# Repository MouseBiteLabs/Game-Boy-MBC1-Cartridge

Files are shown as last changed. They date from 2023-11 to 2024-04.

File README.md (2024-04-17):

# Game Boy MBC1 Cartridge

This is my design of a flashable MBC1-based cartridge for the Game Boy. The MBC1 mapper was used in many of the earlier Game Boy games, such as the Super Mario Land series, the Donkey Kong Land series, Metroid II, and one of my personal favorites - the original Link's Awakening. 

This circuit board should cover most, if not all, MBC1 games. The features are as follows:

- Able to make games that use 512 KB (4 Mbit) of ROM and 256 Kbit of RAM, or 2 MB (16 Mbit) of ROM and 64 Kbit of RAM
- Compatibility with all four of the major Game Boy battery management ICs - MM1026, MM1134, BA6129, and BA6735
- The option to add battery backup to the cartridge *without* the need of the original battery management ICs - perfect for MBC1 donors that didn't have batteries in them
- Lower battery consumption compared to some of the original cartridges
- Fully compatible with the <a href="https://www.gbxcart.com/">GBxCart RW</a> so you can transfer games and save files to and from the board

assemblepic

boardscan3

All gerbers and source files can be found in this repo, as this project is fully open source. Technical documentation of the board can be found in the Technical folder.

## Important Things Before You Start

1) To use this board, you need to have an original Game Boy game that uses an MBC1 mapper chip. <a href="https://catskull.net/gb-rom-database/">You can find a list of games and their mappers here</a>. Use the search function. Please note the RAM is in bytes, not bits. Since SRAM in this repo is defined in bits, you need to convert by multiplying the number of bytes by 8.
2) You will need to remove the MBC1 from your donor cartridge for use on this board. This will require a hot air rework station or a hot plate. There's a list below of other parts you can re-use from the donor cartridge.
3) When soldering parts on, it's a good idea to put kapton tape or otherwise cover the bottom cartridge edge. You do not want to get solder on the cartridge contacts.
4) I am not responsible for any damage you do to your self or your property. Attempt this project at your own risk.
5) I do not guarantee design compatibility. You may encounter issues with certain games. There is also a chance I have made an error in the design or the BOM - if this is the case, I will do everything I can to address the problem as quickly as possible.
6) If you are using this board to make games other than for personal use, you must have permission from the originator to use and distribute any ROM images or other related material. You are responsible for making sure you adhere to any license requirements.

DO NOT use my circuit boards for profiting from stolen work - this especially includes homebrew content, ROM hacks, and using fan-made labels without permission from the originator. **Support original creators!**

## Board Characteristics and Order Information

The zipped folder contains all the gerber files for this board. The following options **must** be chosen when ordering boards for yourself.

- Thickness: 0.8mm
- Surface Finish: ENIG
- Gold Fingers: Yes, 30° chamfer

**I sell this blank circuit board on Etsy, so you don't have to buy a bunch of multiples if you don't want to.** (Click the banner!)

<a href="https://mousebitelabs.etsy.com/listing/1605236472/game-boy-cartridge-pcb-mbc1">PCB from Etsy</a> 

You can alternatively use the zipped folder at any board fabricator you like. You may also buy the board from PCBWay using this link (disclosure: I receive 10% of the sale value to go towards future PCB orders of my own):

<a href="https://www.pcbway.com/project/shareproject/Game_Boy_MBC1_Cartridge_9115d770.html">PCB from PCBWay</a>

<a href="https://oshpark.com/shared_projects/bYJcF53Z">The board is also listed on OSH Park as well.</a> **Be sure to get them in 0.8mm thickness if you order from here.**

## Required Equipment

The EEPROMs on the board needs to be programmed somehow. I recommend using the GBxCart, as mentioned. These boards are fully compatible with it, and it makes reflashing games extremely easy using <a href="https://github.com/lesserkuma/FlashGBX">lesserkuma's FlashGBX software</a>.

Alternatively, you can buy an EEPROM programmer with a TSOP adapter. The downside to this method is that you have to desolder the chip every time you want to program it. The <a href="https://flashcatusb.com/">FlashcatUSB</a> is one popular option in retro spaces.

## Battery Safety

When assembling a board, I recommend populating all the parts *except* the battery, and getting it to run initially without it. This is to make it easier to fix any solder connections that might need fixing, without having to worry about getting the battery hot. And if you need to rework anything near the battery after you've put it on the board, be safe and remove it before putting a hot soldering iron next to it.

And this should go without saying, but if you're assembling these boards with a hot plate or hot air, *do not* solder the battery on this way. You should use an iron, and keep heat off of the battery as much as possible. 

(Also check polarity!)

## Board Configurations

The board comes with four sets of jumper pads for solder bridges. SJ1 and SJ2 require you to solder bridge the middle pad either to the top pad or the bottom pad. SJ3 and SJ4 are configured by either leaving them alone or bridging them with solder. Here are the situations where you need to add solder bridges.

### RAM Size Selection (SJ1 and SJ2, or SW1)

These two sets of pads are labelled "RAM SIZE" in the middle of the board. Soldering them will configure the max RAM *and* ROM size. You must configure these pads for every game you make - do not leave them empty (if you have no SRAM, solder to the "64K" setting to maximize ROM space). <a href="https://catskull.net/gb-rom-database/">You can find a list of games here with their respective ROM and RAM sizes.</a>

- Solder bridge SJ1 and SJ2 from their middle pads to the top pads for games that have larger ROM sizes (up to 2 MB, or 16 Mbit of ROM, and up to 64 Kbit of RAM).

- Solder bridge SJ1 and SJ2 from their middle pads to the bottom pads for games that have larger RAM sizes (up to 512 KB, or 4 Mbit of ROM, and up to 256 Kbit of RAM).

- SJ1 and SJ2 must be soldered in the same direction.

- The footprint of these selection pads should allow for a DPDT switch, part number CAS-220A1, to be placed on these pads instead of having to bridge the pads with solder.



### Using an MM1134 or BA6735 for U4 (SJ3)

Bridge the jumper SJ3 if you have either an MM1134 or BA6735 for U4, specifically. Any other battery management IC must leave SJ3 unsoldered.

### Making Games Without RAM (SJ4)

If your game does not have RAM on it (and therefore, you don't need the battery management IC U4), bridge SJ4 with solder. **Do not** bridge SJ4 if you are using U5 (TPS3613) instead of U4.

## Test Points and Final Checkout

On the back of the board are five test points. Here's where they are connected:

- TP1: SRAM supply voltage
- TP2: Battery voltage (after R1)
- TP3: Battery voltage (positive terminal of battery)
- TP4: Ground
- TP5: VCC input voltage

After you assemble your game, you should measure the current out of the battery. But first, you should program it with the GBxCart, or if you programmed the EEPROM separately, put it into a Game Boy and cycle power once. Then, flip the PCB upside down on a non-conductive surface (not your leg), and set your multimeter in DC millivolts (or volts). Put the positive probe on TP3 and the negative probe on TP2. If you used a 10kΩ for R1, as indicated in the BOM, you should read a voltage in the single of millivolts. If you have something much higher, especially voltages above 30mV, then you likely have an issue or short circuit on the board somewhere.

**Note: You need to power up the game at least once before battery currents will make sense - the battery management ICs can start up in an unknown state before applying main power to the board.**

To estimate battery life, see <a href="https://github.com/MouseBiteLabs/Game-Boy-MBC1-Cartridge/tree/main/Technical#estimating-battery-life">this section in the Technical Design Document</a>, or for more in-depth analysis, <a href="https://hackaday.io/project/11864-tritiled/log/72554-determining-maximum-runtime-176-to-202-years-cr2032">this Hackaday post</a>.

### Why not FRAM?

This board is only suitable for using SRAM. One downside to SRAM, if you haven't figured it out yet, is that you need a battery to keep the SRAM powered on even when the game is turned off. So eventually the battery will die, and your save data is lost. Some people have used FRAM, or Ferroelectric RAM, to keep save data around even after the battery dies (specifically, the popular part that's used for FRAM carts is the FM18W08). But, using this FRAM chip has a handful of downsides, and the benefit of keeping save data after the battery dies *in my opinion* does not outweigh the cons, which are as follows:

1) Quality, new stock, 5V tolerant FRAM is expensive ($12+ per part).
2) Cheaper FRAM chips from eBay or Aliexpress are notoriously flaky (anecdotally, ~50% success rate).
3) FRAM memory access requires different chip select timing than SRAM, and the Game Boy expects SRAM, so it is not natively compatible with FRAM carts. The Gameboy Color specifically cannot (easily) be made to properly access FM18W08 chip. You *can* use an OR gate and add the CLK on the cart edge to try to achieve the necessary timing, but it only works (properly) for DMG/MGB/SGB, not the GBC. It usually *works* in practice for GBC, but it's technically a datasheet violation and can potentially cause issues in edge cases. <a href="https://github.com/Gekkio">(Thanks to gekkio for pointing this out!)</a>

Brand new SRAM chips are ~$3, and having the SRAM footprint also allows you to use SRAM from an original cart if desired. You will *easily* get more than a decade of life running on a battery. You're already assembling this cartridge; you can dump the save and replace the battery before then!

Note that this isn't to throw shade at any FRAM-based carts, but for me personally, it's more trouble than it's worth.

## Board Fitment

The shape of this board was originally meant to mimic original Game Boy circuit boards as closely as possible (v1.3 and earlier). Unfortunately, when placed in some aftermarket Game Boy cartridge shells (like those from Cloud Game Store), the circuit board has a lot of freedom to rotate around the main screw hole in the bottom-middle of the cartridge. This can cause misalignment when you put it in a Game Boy, which can cause a game to either not load properly (garbled Game Boy logo) or shut off the Game Boy because of a short circuit. This isn't *dangerous* or anything, just annoying.

In order to make the boards fit nicer in any kind of shell, for v1.4 I added extended tabs of circuit board material to the edges of the cartridges to keep it from rotating too much in shells, which was suggested to me by <a href="https://github.com/orangeglo">orangeglo</a>! (Thanks!)

If you're having trouble fitting the circuit board into a shell, because the tabs interfere with the cart edges, you can safely sand or trim them down as there is no copper within the tabs themselves. The only shell that appears to require any kind of trimming are Kitsch-Bent shells.

## Bill of Materials (BOM)

Your parts list will vary depending on the game you are trying to make, and what chips you have for the battery management (if any). **You cannot use both U4 and U5 - you must choose one or the other.** U4 comes from a donor cartridge, and U5 is a readily available aftermarket option.

Please carefully review the parts you need for the board you are trying to make. Do not add any parts to your build that don't appear in the column for the game you are making. This means you *cannot* populate every component on the board at the same time.

| Reference Designators | Value/Part Number | Package | Description | No save carts | Save carts with MM1134 or BA6735 | Save carts with MM1026 or BA6129 | Save carts without donor U4 chip | Source |
| --- | --- | --- | --- | --- | --- | --- | --- | --- |
| B1 | CR2032, CR2025, CR2016 | CR2032 | Backup Battery | | x | x | x | [https://mou.sr/3SeAzfT](https://mou.sr/3SeAzfT) |
| C1 | 0.1uF | 0603 | Capacitor (MLCC) | x | x | x | x | [https://mou.sr/3ENc15O](https://mou.sr/3ENc15O) |
| C4 | 0.1uF | 0603 | Capacitor (MLCC) | | x | x | | [https://mou.sr/3ENc15O](https://mou.sr/3ENc15O) |
| C5 | 0.1uF | 0603 | Capacitor (MLCC) | | x | x | x | [https://mou.sr/3ENc15O](https://mou.sr/3ENc15O) |
| C6 | 10uF | 0603 | Capacitor (MLCC) | | x | x | x | [https://mou.sr/3mZtSkF](https://mou.sr/3mZtSkF) |
| C7 | 0.1uF | 0603 | Capacitor (MLCC) | x | x | x | x | [https://mou.sr/3ENc15O](https://mou.sr/3ENc15O) |
| C8 | 0.1uF | 0603 | Capacitor (MLCC) | | | | x | [https://mou.sr/3ENc15O](https://mou.sr/3ENc15O) |
| Q1 | 2N7002 | SOT-23 | N-Channel FET | | | | x | [https://mou.sr/3rgfh6J](https://mou.sr/3rgfh6J) |
| Q2 | 2N7002 | SOT-23 | N-Channel FET | | | x | | [https://mou.sr/3rgfh6J](https://mou.sr/3rgfh6J) |
| R1 | 10k | 0603 | Resistor | | x | x | x | [https://mou.sr/3riR7IH](https://mou.sr/3riR7IH) |
| R3 | 49.9k | 0603 | Resistor | | x | x | x | https://mou.sr/3Q3NRZO |
| R4 | 49.9k | 0603 | Resistor | | x | x | x | https://mou.sr/3Q3NRZO |
| R5 | 49.9k | 0603 | Resistor | x | x | x | x | https://mou.sr/3Q3NRZO |
| R6 | 49.9k | 0603 | Resistor | x | x | x | x | https://mou.sr/3Q3NRZO |
| R7 | 10k | 0603 | Resistor | | | x | | [https://mou.sr/3riR7IH](https://mou.sr/3riR7IH) |
| R8 | 10k | 0603 | Resistor | x | x | x | x | [https://mou.sr/3riR7IH](https://mou.sr/3riR7IH) |
| R9 | 130k | 0603 | Resistor | | | | x | https://mou.sr/3MjXliy |
| R10 | 49.9k | 0603 | Resistor | | | | x | https://mou.sr/3Q3NRZO |
| U1 | 29F016, 29F032, 29F033 | TSOP-48, TSOP-40 | Flash EEPROM | x | x | x | x | AliExpress or eBay |
| U2 | MBC1 | SOP-24 | MBC1 Mapper | x | x | x | x | Donor MBC1 Game Boy cartridge |
| U3 | AS6C6264, AS6C62256 | SOP-28 | SRAM | | x | x | x | [https://mou.sr/450klcY](https://mou.sr/450klcY) |
| U4 | MM1026, MM1134, BA6129, BA6735 | SOIC-8 | Battery Management | | x | x | | Donor Game Boy cartridge |
| U5 | TPS3613 | MSOP-10 | Battery Management | | | | x | https://mou.sr/45Ir2kh |

*Note that C9 - C11 footprints are only included on the board for strange edge cases that may require them sometime in the future; do not populate! See the technical design document for more information.*

### Usable Donor Cartridge Parts

You can use a few parts from the donor cart on the new board to save some money. Note that you will generally get better reliability with new parts as opposed to old ones. For example: I have seen failed RAM chips from donors in the past.

1) **U2: MBC1** - This one is required
2) **U3: SRAM** - You can use this part *only if* the game you're making uses the same or less amount of RAM that the donor cartridge does
3) **U4: Battery Management IC** - Using this is probably preferred over the TPS3613 because it'll save you money and parts to put on

You could probably transfer over most of the 0.1uF capacitors but they're pretty cheap anyway, so I generally just recommend buying new resistors and capacitors.

### Capacitors C9 to C11

If you want to experiment with the capacitors C9 to C11, see this info below. **Be aware that adding these components in some of my tests actually ***stopped*** games from working, so again, assume that if you have a problem it lies elsewhere first, because it almost certainly does.**
- C9 is a capacitor connected nearby the MBC1's /WR pin to GND. These were populated on some cartridges, and have a value of approximately 1 nF (0.001 uF).
- C10 is a capacitor connected nearby the MBC1's /RESET pin to GND. A spot for this capacitor was included on some MBC1 carts, but I cannot locate an instance of it actually being used when looking through the gbhwdb. I don't actually know what value this capacitor would need to be, so I am guessing 1 nF.
- C11 is a capacitor that I have added that was not used on any original Game Boy board. It connects to the SRAM's /CE pin, bypassing to GND. I have added this in the event incompatibilities arise with newer SRAM chips that have much faster speeds than older SRAM chips. This was a problem I encountered on some of my NES cartridges, so this is here just in case, but I have not found an instance where it's required.

## Things to Remember

- The footprint for the EEPROM is specifically for 29F016 - it has 48 pins. However, 29F032 and 29F033 are only 40 pin devices. They still work fine on the board though - place them in the center of the footprint, and leave the outer two pins on each corner empty
- The 29F016, 29F032, and 29F033 have been known to occasionally be defective upon arrival. They're either used, or new old stock, and usually only available from AliExpress.
- The footprint for the battery can fit a CR2032, CR2025, or CR2016 with solder tabs. The only difference is the mAh capacity (larger number = longer life). If you get Panasonic tabbed batteries, you may have to trim the battery tabs to make them fit on the footprint.
  - For untabbed coin cells, you can find battery retainer adapters online, <a href="https://retrogamerepairshop.com/products/hdr-game-boy-game-battery-retainer?variant=40511013290156">like this one,</a> but only for board revision v1.4. It will not fit on earlier revisions.
- For battery management, use either U4 *or* U5 and supporting components. **Do not** use U4 and U5 simultaneously on one board. They will interfere with each other.
- Generally, ROM sizes are conveyed in terms of kilo**bytes** and mega**bytes** (KB, MB). RAM size is usually conveyed in terms of kilo**bits** or mega**bits** (Kbit, Mbit). You can convert Kbit and Mbit to KB and MB by dividing Kbit or Mbit by 8. For example, 256 Kbit = 32 KB.
- You only need to provide ROM and RAM chips that have at least *or greater* the size of the game you are trying to make. That means you can use a 256 Kbit SRAM chip for a game that only requires 64 Kbit of RAM!

## Labels

If you want a Bucket Mouse branded label for your cartridge, look no further than <a href="https://krizdingus.com/mousebitelabs/">krizdingus's designs</a>. Special thanks to Kris for designing these, they look awesome! (If you are going to order/print these, use the high-res images hosted on his website, and *keep the labels for personal or non-commercial use only.*)



## Revision History

### v1.4
- Reduced cart edge by 0.1 mm for better fitment
- Adjusted battery placement to support more battery holders
- Added tabs on the board edges to allow the circuit board to fit better in aftermarket cartridge shells

### v1.3
- Extended cart edge down by 0.25 mm for better fitment
- Added OSHW logo and "SUPPORT ORIGINAL CREATORS!"

### v1.2
- Replaced non-donor battery management circuitry with a TPS3613-based circuit for smaller BOM and easier routing

### v1.1
- Moved all parts on the top down to allow for compatibility with DMG-style shells
- Rotated battery for more space
- Widen SRAM footprint for easier soldering
- Renamed some reference designators for consistency between designs
- Changed silkscreen for clarity

### v1.0
- Prototype revision

## Resources and Acknowledgements

- <a href="http://www.devrs.com/gb/files/hardware.html">Jeff Frohwein's GameBoy Tech Page</a>
- <a href="https://gbhwdb.gekkio.fi/">Game Boy Hardware Database</a>
- <a href="https://catskull.net/gb-rom-database/">Nintendo Gameboy Game List</a>
- <a href="https://wiki.tauwasser.eu/view/MBC1">Tauwasser's Wiki</a>
- <a href="https://www.gbxcart.com/">insideGadgets discord server for GBxCart RW compatibility requirements</a>
- <a href="https://github.com/lesserkuma/FlashGBX">Lesserkuma's FlashGBX software</a>
- <a href="https://www.alldatasheet.com/datasheet-pdf/pdf/99104/MITSUBISHI/MM1026.html">System Reset IC Datasheet</a>
- <a href="https://www.ti.com/lit/ds/symlink/tps3613-01.pdf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">TPS3613 Datasheet</a>
- Board outline modified from <a href="https://tinkerer.us/projects/homebrew-gameboy-cartridge.html">Dillon Nichols's Homebrew Gameboy Cartridge project</a>
- Thanks to <a href="https://github.com/orangeglo">orangeglo</a> for his suggestion of adding spacers around the board edge for better fitment in aftermarket cartridges
- Some components from <a href="https://github.com/adafruit/Adafruit-Eagle-Library">Adafruit's Eagle parts library</a>
- Some components from <a href="https://www.snapeda.com/">SnapMagic</a>
- Thank you to <a href="https://github.com/Gekkio">gekkio</a> for their deep Game Boy knowledge resources, and for collaboration in demystifying some of the design choices on Game Boy cartridges
- Thanks to the awesome members of the <a href="https://moddedgameboy.club/">Modded Gameboy Club</a> for their feedback and support during the entire project development

## License

<br />This work is licensed under a <a rel="license" href="http://creativecommons.org/licenses/by-sa/4.0/">Creative Commons Attribution-ShareAlike 4.0 International License</a>. You are able to copy and redistribute the material in any medium or format, as well as remix, transform, or build upon the material for any purpose (even commercial) - but you **must** give appropriate credit, provide a link to the license, and indicate if any changes were made.

©MouseBiteLabs 2023

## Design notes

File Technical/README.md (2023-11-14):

# Technical Design Document 

This write-up will serve as an attempt of explaining some of the features on this cartridge. I won't go into heavy detail about the functionality of the MBC1, but I will attempt to explain some higher level functions and the reasoning behind the circuit.

Please correct me on any information I may have gotten wrong.

## Schematic



## Cart Edge Pins

Very briefly, I will categorize the different pins on the 32-pin cartridge edge connector.

- Pin 1 and pin 32 are VCC and GND, respectively.
- Pin 2 is the CLK or PHI pin. These are not used on the MBC1 cartridge.
- Pin 3 is the /WR pin, pin 4 is the /RD pin, pin 5 is the /CS pin. These signals partially determine when data is read from the ROM or when data is read/written to the RAM.
- Pins 6 through 21 are the address pins A0 through A15.
- Pins 22 through 29 are the data pins D0 through D7.
- Pin 30 is the /RST (or reset) pin. When this pin is low, the Game Boy will cease operation.
- Pin 31 is a generally unused pin in Game Boy cartridges, but here it is connected to the EEPROM's /WE pin for compatibility with the GBxCART RW.

## MBC1 - Memory Bank Controller

The MBC1 is a pretty simplistic memory mapping chip. I won't go into detail how it operates, because you can find sufficient explanations from <a href="https://wiki.tauwasser.eu/view/MBC1">Tauwasser's website</a>, among others. A high level explanation is that it is used to expand the addressable memory of a Game Boy cartridge. The RA14-RA18 and AA13-AA14 outputs are used to access higher memory banks on the ROM and RAM chips. It also has ROM and RAM chip select outputs to control data access on the ROM and RAM chips, though only the RAM /CS output is commonly used.

Further sections will provide more context for some of the MBC1 pins and the logic of how they are connected.

## ROM and RAM

The connections to the address and data pins here are mostly self-explanatory. However, the upper address pins are controlled by the MBC1.
- A14 through A18 on the ROM chip are controlled by the RA14 to RA18 outputs from the MBC1.
- A19 and A20 on the ROM, and A13 and A14 on the RAM, are both controlled by the MBC1's output pins 6 and 7 - but you can only select one set of pins, not both!
  - This means you can use the MBC1 for games with 512 KB (4 Mbit) of ROM space and 256 Kbit of RAM space, *or* 2 MB (16 Mbit) of ROM space and 64 Kbit of RAM space. On my cart, this is selected with SJ1 and SJ2.
  - R3 through R6 on my cart are pull-down resistors for asserting the unused set of two pins to known states to prevent unwanted behavior.
    - In 64K SRAM mode: R3 will pull pin 26 on the SRAM to the CS_OUT pin (which connects to the MM chip CS output pin or the /RESET output pin of TPS3613). On 64K SRAM chips, this is the CE2 pin, and it's normally wired this way on regular carts for low-power data retention mode. If you use a 256K SRAM chip instead, then this is the A13 address pin, and will go unused if using it in 64K mode.
    - In 64K SRAM mode: R4 will pull pin 1 on the SRAM to GND. This is NC on 64K SRAM chips, and A14 on 256K SRAM chips which will be unused in 64K mode.
    - In 256K SRAM mode: R5 and R6 will pull the upper unused address pins of the EEPROM to GND.



Other pins include: 

- The ROM's /CE pin is controlled by the A15 address pin and the /OE pin is controlled by the /RD pin on the cart edge (pin 4).
- The ROM's /WE pin, which was not on original cartridges, is connected to pin 31 on the cart edge for programming via the GBxCART RW as previously mentioned.
- The RAM's /OE pin is connected to the /RD pin on the cart edge (pin 4).
- The RAM's /WE pin is connected to /WR on the cart edge (pin 3).
- The RAM's /CE pin requires a bit of explanation, which will be covered in a later section.

## Battery Management and Data Retention Considerations

Ensuring current coming out of the battery is as minimal as possible while the Game Boy is turned off is crucial for long-lasting save data. The higher the current, the lower the battery life! But we need to do this without breaking compatibility with normal operation. So here are the things we need to keep in mind:

1) SRAM must have continuous power to retain save data.

2) Data on the SRAM must be accessible during normal gameplay.

3) The number of battery-powered current-consuming components should be minimized, and those that are powered must use as little current as possible.

4) Operation while the voltage is ramping down after turning off the power switch must be restricted to prevent junk data from being written to cartridge RAM.

Original MBC1 carts manage all of this with U4, which was typically MM1026 or the equivalent BA6129. The MM1134 or the equivalent BA6375 can also be used. I'll go over the functional requirements here, and for convenience, I'll be using the MM numbers when talking about them.

### SRAM Operational Background

For most Game Boy games, there were two main sizes of SRAM chips used - 64 Kbit and 256 Kbit (further refered to as just 64K or 256K). The pinouts of these two types of chips are nearly identical: 



The big differences are the number of address pins and the number of chip enable pins. The 64K chip has 13 address pins and two chip enables (/CE and CE2), and the 256K chip has 15 address pins and one chip enable (just /CE). The additional address pins on the 256K SRAM gives it more memory, but one of the chip enable pins had to be sacrificed to accommodate this. This is kind of important, because the chip enable pins influence two main things - they tell the chip when data is being accessed, *and* how much current the chip is drawing during standby. For 64K SRAM chips, that's pretty easy - use one chip enable pin for data access, and the other for data retention mode. But for 256K SRAM, you have to do both of those functions at once. Look at the requirements for the low "data retention current" on the AS6C6264 datasheet and the AS6C62256 datasheet:



For 64K, /CE needs to be at VCC, *or* CE2 needs to be at GND for the current to be minimized. For 256K, /CE needs to be at VCC, full stop (in this case, VCC is whatever voltage appears on the SRAM's VCC pin, so when power is off that's the battery voltage). That's not super convenient if the power is off - something needs to make the /CE pin go to VCC, which means whatever that something is better not be pulling a lot of current, lest we lower our battery life.

On original MBC1 cartridges, games that have 64K SRAM used the MBC1 for controlling the /CE pin for data access, and U4 (MM1026) for keeping CE2 at GND when power was off. But for 256K SRAM, that CE2 pin wasn't available anymore. Instead, if a cartridge had an MM1026 chip for battery management, the MBC1 was powered via of the battery as well, and had internal logic to keep /CE logic high when disabled. The MM1026 has a /CE output as well that will pull the output up to the battery voltage, however it *does not* have a way to allow the /CE pin to be accessed during normal gameplay. So the MBC1 needs to take care of both functions, but since it's powered from the battery when power is off, that means the battery life would be impacted. I don't know how much current the MBC1 pulls from the battery for games that had 256K SRAM, but I imagine it probably wasn't a whole lot - I would still expect 64K SRAM games to last longer though.

*Wouldn't it be great if there was some version of this MM chip that utilized some kind of function that combined regular access of the 256K SRAM's /CE pin but also keep it pulled up to battery voltage when power was shut off for low data retention currents without having to power the MBC1 on the battery as well? ..... Foreshadowing is a literary device in whi ---*

On my custom MBC1 board, I implement a method of accessing the RAM /CE pin *and* keeping it in a low power state, without needing the MBC1 to be powered by the battery. This can be done with just an MM1134, an MM1026 and extra parts, or completely new off-the-shelf components without the need for a donor. But before covering that, let's talk about the other important part of the battery backup system - how to properly and safely manage shifting between console power to battery power.

### Reset IC - MM1026

When you turn the power switch off on a DMG, the voltage on the VCC supply will ramp down. However, the DMG CPU requires 5 V to operate properly. A sufficiently lower voltage supplying the CPU may cause erroneous operation on the I/O pins of the CPU, even for a brief period of time. This can corrupt data stored on the SRAM of the game cartridge, say if the CPU accidentally writes junk data to part of the memory. This is bad! 

In order to prevent this, cartridges that have battery-backed SRAM on them use the battery management chip U4 to shut down operation of the CPU on pin 30 of the cart edge - the /RST (or /RESET) line. Asserting this to GND will stop all operation on the I/O pins, preventing corruption from occuring. According to the MM1026 datasheet, the /RESET output and CS output pins will be GND whenever voltage on the VCC pin is below 4.2V.

*Please note that the MM1026 has a /RESET output pin, but this is not the same as the Game Boy CPU /RESET input, the MBC1 /RESET input, or the cart edge /RST pin 30! I will call the MM1026's pin 2 the "Reset output pin" from now on for clarity.*



But that's not all the MM chip does. It also is used to pull the MBC1's /RESET input to GND as well. This is especially important for original Game Boy MBC1 carts with 256K SRAM that needed the MBC1 to be powered from the battery, as keeping this pin off will (assumedly) keep current draw of the MBC1 to a minimum. Furthermore, pulling this pin to GND also causes the MBC1 to assert the SRAM's /CE pin high to keep the SRAM in a low power state.

### Reset IC - MM1134

The MM1134 is nearly identical to the MM1026, with one distinct difference. There is one extra input that was previously an unconnected pin on the MM1026 - the /Y input. This input is intended to be used with a RAM /CE signal. It controls the /CS output (pin 5) on the MM1134. See the schematic and timing diagram below:



Essentially, the /CS output will follow the /Y input, *unless* VCC is below the 4.2V power-off threshold. Then, /CS will be pulled to VOUT (the combination of VCC and VBAT). Hey, this is great, because it means we can control that pesky 256K SRAM /CE pin *and* put it in a low power state when the power shuts off!

*Note: If you ground the /Y input, then the MM1134 will act exactly like an MM1026.*

On the gbhwdb, there are only a few cartridge PCBs that use an MM1134 (the BA6735 equivalent, specifically) - DMG-DECN-20 and DMG-DGCU-10 - but these boards use 64K of SRAM, so this extra /Y pin goes unused. 

### Open Collector Requirements on CPU /RESET Input

One minor, but important, note that drives a few design choices - there are actually two outputs on the MM1026/MM134 that go low when power is below 4.2 V. One of them is open collector (pin 2, the "Reset output"), and one is instead driven high by an internal transistor or pulled low by an internal pull-down (pin 3, the "CS output"). This is important because it means *you cannot safely use the CS output pin to control the Game Boy's /RESET line.*



On the DMG, the CPU's /RESET input is also connected to half of the power switch. When the switch is fully turned off, the /RESET input is pulled to GND directly.



*[Image adapted from <a href="https://github.com/Gekkio/gb-schematics/blob/main/DMG-CPU-06/schematic/DMG-CPU-06.pdf">gekkio's DMG CPU board schematic</a>]*

This means that to ensure no damage is done to the battery management chip, any output connected to the Game Boy's /RESET input must be **open collector**. Open collector outputs can either float their output, or (in this case) pull it to GND - reference the "Pin 2 Reset Output" schematic above. That means pulling it to GND with the power switch won't damage anything internal to the chip, it will just safely bypass the pin's function.

But, in the case of pin 3 on the MM chips, the "CS output" pin, imagine a scenario where the power switch was turned off, but the capacitors on the board have not yet discharged down to 0V. This means there'd still be some residual voltage on the VCC net. But, the CS output pin is connected to VCC via the transistor internal to the chip, and if VCC hasn't dropped far enough, then this would still be pulled high to VCC. So if you had connected pin 3 to the /RESET input on the Game Boy, in this scenario, there would be a path from VCC on the MM's supply pin, *through* the transistor on pin 3, through the power switch on the DMG, to GND - short circuiting the capacitors on the board. This means that for a moment, the internal transistor driving pin 3 would experience a surge of current. Since the output is not designed to do that, it could cause damage to the part. So let's avoid that situation!

In conclusion, any output connected to the /RESET net on the Game Boy *must* be open collector.

*On the GBC, they added a chip that pulls the /RESET line to GND through an open collector output whenever the voltage on VCC drops below 3.5 V, instead of using the power switch to ground the input. If the DMG had this, maybe Nintendo wouldn't have needed these MM chips but could use something a bit simpler. But we must design cartridges with DMG compatibility in mind!* 

## Battery Management Implementation Options

Ok, with the background taken care of, I'll talk about how my MBC1 board manages all of this, and the different compatibility options. If you reference the schematic above, you will see three options for games that use SRAM:
1) MM1134 ("Group A" components)
2) MM1026 ("Group A" and "Group C" components)
3) No donor MM chip ("Group B" components)

### Using an MM Chip

For reference again, here is a pinout diagram of the MM1026 and MM1134.



And here is the section of the schematic for using one of these chips ("Group A" components).



#### Creating the Battery-Backed Power Supply

The VOUT pin is a combination of the VCC and VBAT pins. VCC is connected to the Game Boy's 5V supply, and VBAT is connected to the battery (through a current-limiting resistor). When VCC drops below 3.3V during power-down, the MM chip switches VOUT to be supplied by VBAT instead of VCC. Conversely, when it passes above 3.3V during power-on, the MM chip switches VOUT to be supplied by VCC instead. This guarantees constant power to the SRAM to keep save data retained at all times, assuming the battery is not dead.

#### Reset Pin Management

Because anything connected to the /RESET input pin on the cart edge must be open collector, the open collector output of the MM chip, pin 2, is connected to the /RESET cart edge pin (pin 30). The MBC's /RESET input, pin 10, is connected to the driven CS output of the MM chip, pin 3.

#### Controlling the SRAM /CE Pin (MM1134)

The RAM_/CS output of the MBC1 is connected to the /Y input (pin 7) of the MM1134, and if SJ3 is bridged to connect it to RAM_/CS_G (as it should be when using an MM1134), the /CS output (pin 5) will be connected to the SRAM /CE input. As explained earlier, the state of the /CS output of the MM1134 is the same as the /Y input, unless VCC is below 4.2V, in which case the /CS output is pulled up to the VOUT voltage to satisfy low-current data retention requirements of the SRAM.

#### Controlling the SRAM /CE Pin (MM1026)

Because the MM1026 does not have the gated /CS output functionality, and the MBC1 is not powered by the battery on my cart design, we need to add the function back with some external components, which I have labelled as "Group C" components in the schematic.



As a reminder: RAM_/CS connects to the MBC1's RAM_/CS output pin, RAM_/CS_G connects to the SRAM's /CE input, and VCC_SRAM connects to the MM1026 VOUT pin.

- When the CS output is driven low (when VCC is below 4.2V), conduction between the drain and source of Q2 will be off; the RAM_/CS_G net will be pulled up to the battery-backed voltage via R7, no matter what RAM_/CS is doing.
- When the CS output is driven high (when VCC is above 4.2V), conduction between the drain and source of Q1 is allowed; RAM_/CS_G will follow the RAM_/CS output, which will allow the MBC1 to control the SRAM /CE input.

Thus, this circuit essentially adds the MM1134's gated /CS output functionality back into the circuit.

### Using Brand New Components

If you do not have one of these MM chips, as you can only typically get them from donor Game Boy cartridges and not all games use them, you can achieve the same results using commercially-available components. In order to do so, you need to populate "Group B" components which features the TPS3613 - a Texas Instruments chip that is almost identical to the MM1134, with a few minor differences.



Here is the timing diagram from the TPS3613 datasheet, showing the relations between the inputs and outputs of the chip.



#### Creating the Battery-Backed Power Supply

Like the MM chips, VOUT is created by VCC or VBAT. But instead of a hard internal threshold, the output of this pin is determined by the voltage on the SENSE pin. If the voltage on SENSE is above an internal set voltage of 1.15 V (shown as VIT in the diagram), VOUT is equivalent to VCC. When the SENSE voltage drops below VIT, and when VCC drops below VBAT, VOUT switches over to being powered by VBAT instead.

The voltage on SENSE is determined by the voltage divider made with R9 and R10. The MM chips have an internal threshold of 4.2 V for determining that the power is going off and the /RESET outputs should be asserted to protect the RAM from spurious writes. So for this design, I'll stick to that threshold.

#### Reset Pin Management

The /RESET and RESET outputs of the TPS3613 are push-pull. This is slightly inconvenient, because it means you cannot directly connect them to the /RST pin on the cart edge (pin 30), because as discussed earlier, any connection to this pin must be open collector. So, we just have to make it open collector (or in this case, open drain). Adding Q1, an N-channel MOSFET, achieves this. 

- When voltage on the SENSE pin is above the internal 1.15V threshold, the /RESET output pin is asserted high allowing the MBC1 to function, and the RESET output pin is asserted low. This will keep Q1 off and allow /RST, pin 30 on the cart edge, to float.
- When voltage on the SENSE pin drops below the internal 1.15V threshold, the /RESET output pin is asserted low turning off the MBC1, and the RESET output pin is asserted high. This will turn Q1 on, and pull pin 30 on the cart edge to GND. Note that the positive RESET output follows the voltage on the VDD pin, so once the 5V supply on the Game Boy depletes, Q1 will be off again, but since there will be no power to the MBC1, this doesn't make a difference.

#### Controlling the SRAM /CE Pin

The /CEIN input and /CEOUT output pins of the TPS3613 act exactly like the /Y input and /CS output pins of the MM1134 - /CEOUT will follow /CEIN as long as the voltage on the SENSE pin is above 1.15V. So the RAM_/CS output is wired similarly to the MM1134 implementation.

## Estimating Battery Life

You can get a very rough estimate of battery life by measuring the voltage in millivolts across the battery-series resistor R1. Just use Ohm's Law to find the current: I = V / R where V is the voltage in millivolts you measure and R is the resistance of R1 in ohms. If you use these units, the current will be in milliamps. 

*Fun fact: you can measure this voltage using TP2 and TP3 on the back of the board as your multimeter probe points.*

Then, find the milliamp-hour rating of your selected battery (preferrably from a datasheet). For example, a Renata CR2025 battery is rated for 165 mAh. Take this number and divide by the milliamps calculated above, to get a rough estimate of the number of hours the battery can supply when the console is turned off (when it is on, the Game Boy powers the cart so the battery is unused). Divide by 24 and then 365 (or just divide by 8760) and you will get a number of years. 

So for an overall equation to determine the very approximate number of years the battery will survive:

Years = Resistance of R1 (ohms) * Battery capacity (mAh) / Voltage (mV) / 8760 

For an example: an MBC1 cartridge where R1 is 10 kΩ (or 10000 Ω), using a CR2025 rated for 165 mAh, and a voltage of 10 mV measured across the terminals of R1, yields 10000 * 165 / 10 / 8760 = 18.84 years of battery survival. This number can be different due to changing environmental conditions, self-discharge of the battery, and also actual capacity of the battery - discharging a battery at very small currents will increase its apparent capacity, and as the voltage decreases, the current required for data retention decreases as well.

Just backup your save data within a decade of making the cart and you'll be fine.

## A Few Extra Capacitors

I added spots for a few extra capacitors, in the event some compatibility issues arise. By default, you should ignore these components, as they were not present in most cartridges. If I find instances where they are needed, I will note them in this repo. For now, assume they are unnecessary.



1) C9 is a capacitor connected nearby the MBC1's /WR pin to GND. These were populated on some cartridges, and have a value of approximately 1 nF (0.001 uF).
2) C10 is a capacitor connected nearby the MBC1's /RESET pin to GND. A spot for this capacitor was included on some MBC1 carts, but I cannot locate an instance of it actually being used when looking through the gbhwdb. I don't actually know what value this capacitor would need to be, so I am guessing 1 nF.
3) C11 is a capacitor that I have added that was not used on any original Game Boy board. It connects to the SRAM's /CE pin, bypassing to GND. I have added this in the event incompatibilities arise with newer SRAM chips that have much faster speeds than older SRAM chips. This was a problem I encountered on some of my NES cartridges, so this is here just in case.

## Resources

- <a href="http://www.devrs.com/gb/files/hardware.html">Jeff Frohwein's GameBoy Tech Page</a>
- <a href="https://gbhwdb.gekkio.fi/">Game Boy Hardware Database</a>
- <a href="https://catskull.net/gb-rom-database/">Nintendo Gameboy Game List</a>
- <a href="https://wiki.tauwasser.eu/view/MBC1">Tauwasser's Wiki</a>
- <a href="https://www.gbxcart.com/">insideGadgets discord server for GBxCart RW compatibility requirements</a>
- <a href="https://www.alldatasheet.com/datasheet-pdf/pdf/99104/MITSUBISHI/MM1026.html">System Reset IC Datasheet</a>
- <a href="https://www.ti.com/lit/ds/symlink/tps3613-01.pdf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">TPS3613 Datasheet</a>
- <a href="https://www.alliancememory.com/wp-content/uploads/pdf/Alliance%20Memory_64K_AS6C6264v2.0July2017.pdf">AS6C6264 Datasheet</a>
- <a href="https://www.alliancememory.com/wp-content/uploads/pdf/AS6C62256.pdf">AS6C62256 Datasheet</a>
- <a href="https://github.com/Gekkio/gb-schematics/blob/main/DMG-CPU-06/schematic/DMG-CPU-06.pdf">Gekkio's Game Boy Schematic Resources</a>

## License
<br />This work is licensed under a <a rel="license" href="http://creativecommons.org/licenses/by-sa/4.0/">Creative Commons Attribution-ShareAlike 4.0 International License</a>. You are able to copy and redistribute the material in any medium or format, as well as remix, transform, or build upon the material for any purpose (even commercial) - but you **must** give appropriate credit, provide a link to the license, and indicate if any changes were made.

©MouseBiteLabs 2023

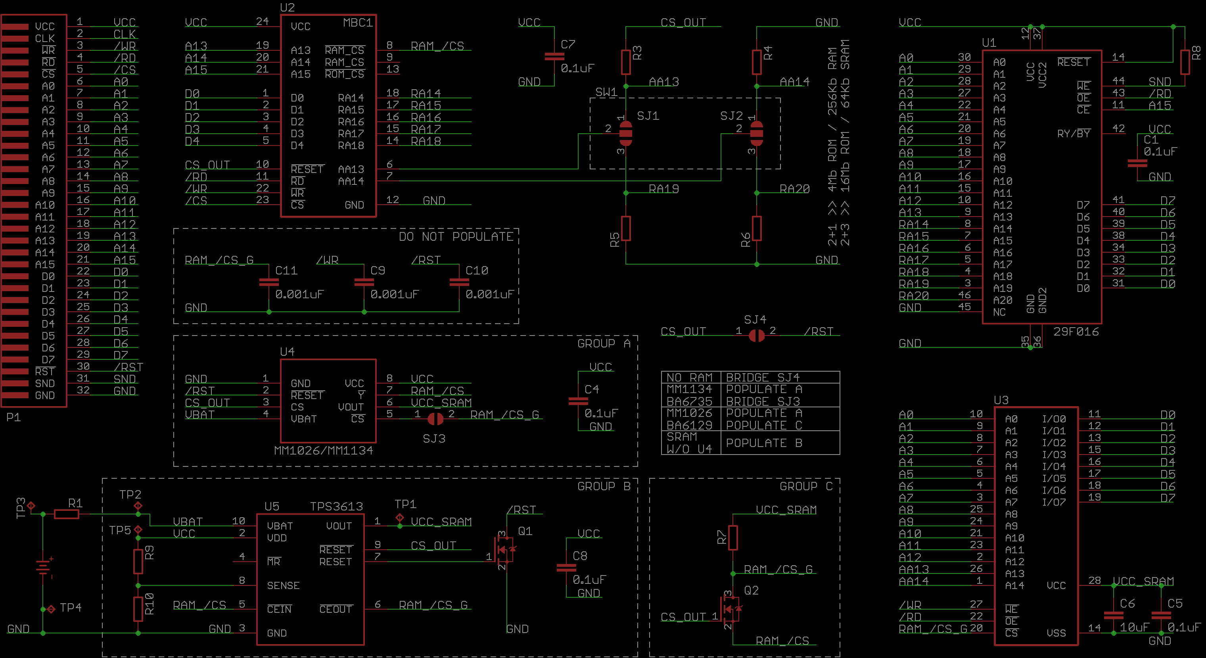
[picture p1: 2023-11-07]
Technical/schematic.png

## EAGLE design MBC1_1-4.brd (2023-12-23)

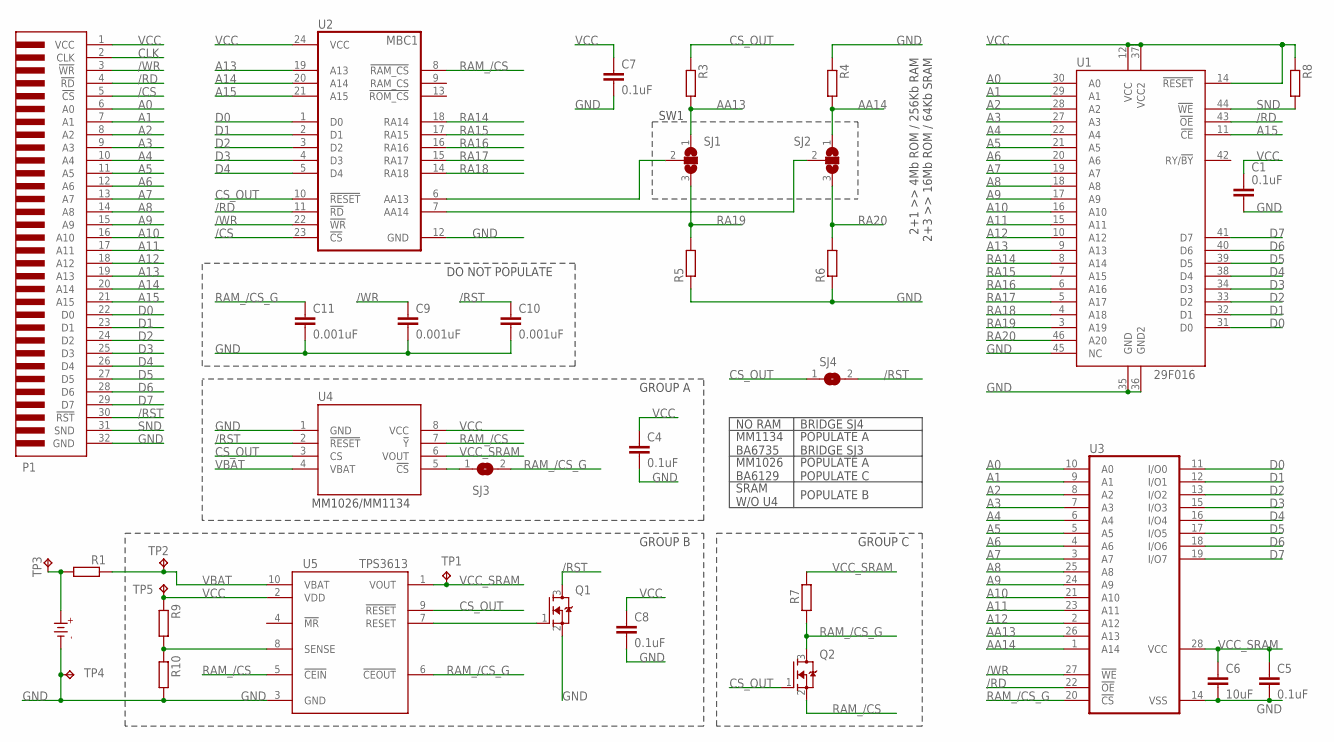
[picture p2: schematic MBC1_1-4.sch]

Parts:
B1: CR2025
C1, C4, C5, C7, C8: 0.1uF; C0603
C6: 10uF; C0603
C9, C10, C11: 0.001uF; C0603
P1: GBC_CARTTAB; GBC_CART_TABBED
Q1, Q2: 2N7002; SOT23
R1, R3, R4, R5, R6, R7, R8, R9, R10: RR0603; R0603
SJ1, SJ2: SJ2W; SJ_2
SJ3, SJ4: SJ
TP1, TP2, TP3, TP4, TP5: TPB1,27; B1,27
U1: 29F016; TSOP-48
U2: MBC1; SOP-24
U3: 62256_SRAM; SOP-28L
U4: MM1134; SOIC-8
U5: TPS3613; MSOP-10

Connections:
/CS: P1.5 (!CS), U2.23 (!CS)
/RD: P1.4 (!RD), U1.43 (!OE), U2.11 (!RD), U3.22 (!OE)
/RST: C10.1, P1.30 (!RST), Q1.3 (D), SJ4.2, U4.2 (!RESET)
/WR: C9.1, P1.3 (!WR), U2.22 (!WR), U3.27 (!WE)
A0: P1.6 (A0), U1.30 (A0), U3.10 (A0)
A1: P1.7 (A1), U1.29 (A1), U3.9 (A1)
A2: P1.8 (A2), U1.28 (A2), U3.8 (A2)
A3: P1.9 (A3), U1.27 (A3), U3.7 (A3)
A4: P1.10 (A4), U1.22 (A4), U3.6 (A4)
A5: P1.11 (A5), U1.21 (A5), U3.5 (A5)
A6: P1.12 (A6), U1.20 (A6), U3.4 (A6)
A7: P1.13 (A7), U1.19 (A7), U3.3 (A7)
A8: P1.14 (A8), U1.18 (A8), U3.25 (A8)
A9: P1.15 (A9), U1.17 (A9), U3.24 (A9)
A10: P1.16 (A10), U1.16 (A10), U3.21 (A10)
A11: P1.17 (A11), U1.15 (A11), U3.23 (A11)
A12: P1.18 (A12), U1.10 (A12), U3.2 (A12)
A13: P1.19 (A13), U1.9 (A13), U2.19 (A13)
A14: P1.20 (A14), U2.20 (A14)
A15: P1.21 (A15), U1.11 (!CE), U2.21 (A15)
AA13: R3.2, SJ1.1, U3.26 (A13)
AA14: R4.2, SJ2.1, U3.1 (A14)
CLK: P1.2 (CLK)
CS_OUT: Q2.1 (G), R3.1, SJ4.1, U2.10 (!RESET), U4.3 (CS), U5.9 (!RESET)
D0: P1.22 (D0), U1.31 (D0), U2.1 (D0), U3.11 (I/O0)
D1: P1.23 (D1), U1.32 (D1), U2.2 (D1), U3.12 (I/O1)
D2: P1.24 (D2), U1.33 (D2), U2.3 (D2), U3.13 (I/O2)
D3: P1.25 (D3), U1.34 (D3), U2.4 (D3), U3.15 (I/O3)
D4: P1.26 (D4), U1.38 (D4), U2.5 (D4), U3.16 (I/O4)
D5: P1.27 (D5), U1.39 (D5), U3.17 (I/O5)
D6: P1.28 (D6), U1.40 (D6), U3.18 (I/O6)
D7: P1.29 (D7), U1.41 (D7), U3.19 (I/O7)
GND: B1.-, C1.2, C4.2, C5.2, C6.2, C7.2, C8.2, C9.2, C10.2, C11.2, P1.32 (GND), Q1.2 (S), R4.1, R5.1, R6.1, R10.2, TP4.TP, U1.35 (GND), U1.36 (GND2), U1.45 (NC), U2.12 (GND), U3.14 (VSS), U4.1 (GND), U5.3 (GND)
unnamed: SJ2.2, U2.7 (AA14)
unnamed: SJ1.2, U2.6 (AA13)
unnamed: B1.+, R1.2, TP3.TP
unnamed: SJ3.1, U4.5 (!CS)
unnamed: Q1.1 (G), U5.7 (RESET)
unnamed: R9.2, R10.1, U5.8 (SENSE)
RA14: U1.8 (A14), U2.18 (RA14)
RA15: U1.7 (A15), U2.17 (RA15)
RA16: U1.6 (A16), U2.16 (RA16)
RA17: U1.5 (A17), U2.15 (RA17)
RA18: U1.4 (A18), U2.14 (RA18)
RA19: R5.2, SJ1.3, U1.3 (A19)
RA20: R6.2, SJ2.3, U1.46 (A20)
RAM_/CS: Q2.2 (S), U2.8 (!RAM_CS), U4.7 (!Y), U5.5 (!CEIN)
RAM_/CS_G: C11.1, Q2.3 (D), R7.1, SJ3.2, U3.20 (!CS), U5.6 (!CEOUT)
SND: P1.31 (SND), R8.2, U1.44 (!WE)
VBAT: R1.1, TP2.TP, U4.4 (VBAT), U5.10 (VBAT)
VCC: C1.1, C4.1, C7.1, C8.1, P1.1 (VCC), R8.1, R9.1, TP5.TP, U1.12 (VCC), U1.14 (!RESET), U1.37 (VCC2), U2.24 (VCC), U4.8 (VCC), U5.2 (VDD)
VCC_SRAM: C5.1, C6.1, R7.2, TP1.TP, U3.28 (VCC), U4.6 (VOUT), U5.1 (VOUT)

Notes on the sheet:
2+1 >> 4Mb ROM / 256Kb RAM 2+3 >> 16Mb ROM / 64Kb SRAM
GROUP A
GROUP C
NO RAM
BRIDGE SJ4
MM1134 BA6735
POPULATE A BRIDGE SJ3
MM1026 BA6129
POPULATE A POPULATE C
SRAM W/O U4
POPULATE B
MM1026/MM1134
GROUP B
DO NOT POPULATE
SW1

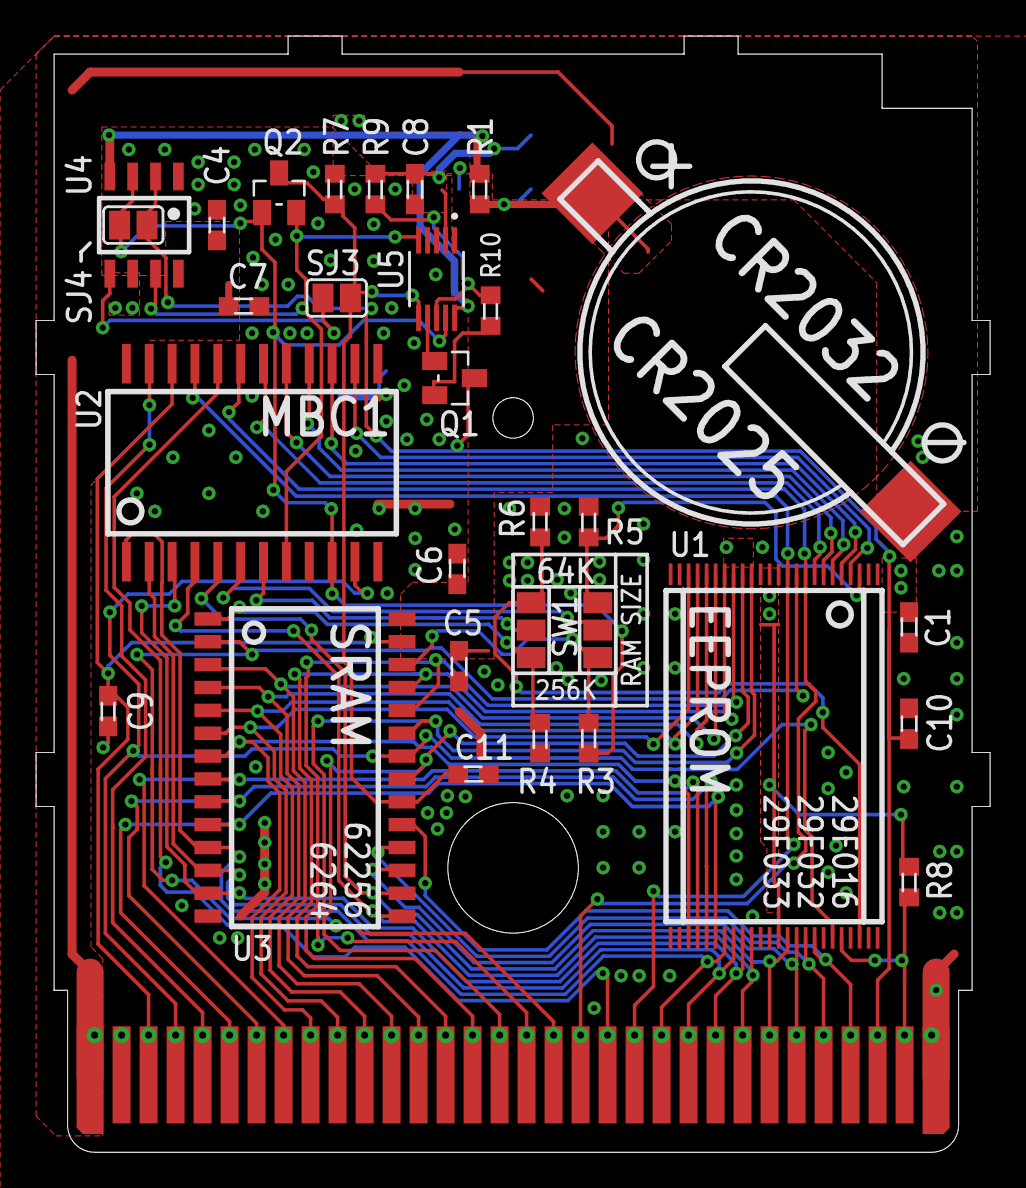
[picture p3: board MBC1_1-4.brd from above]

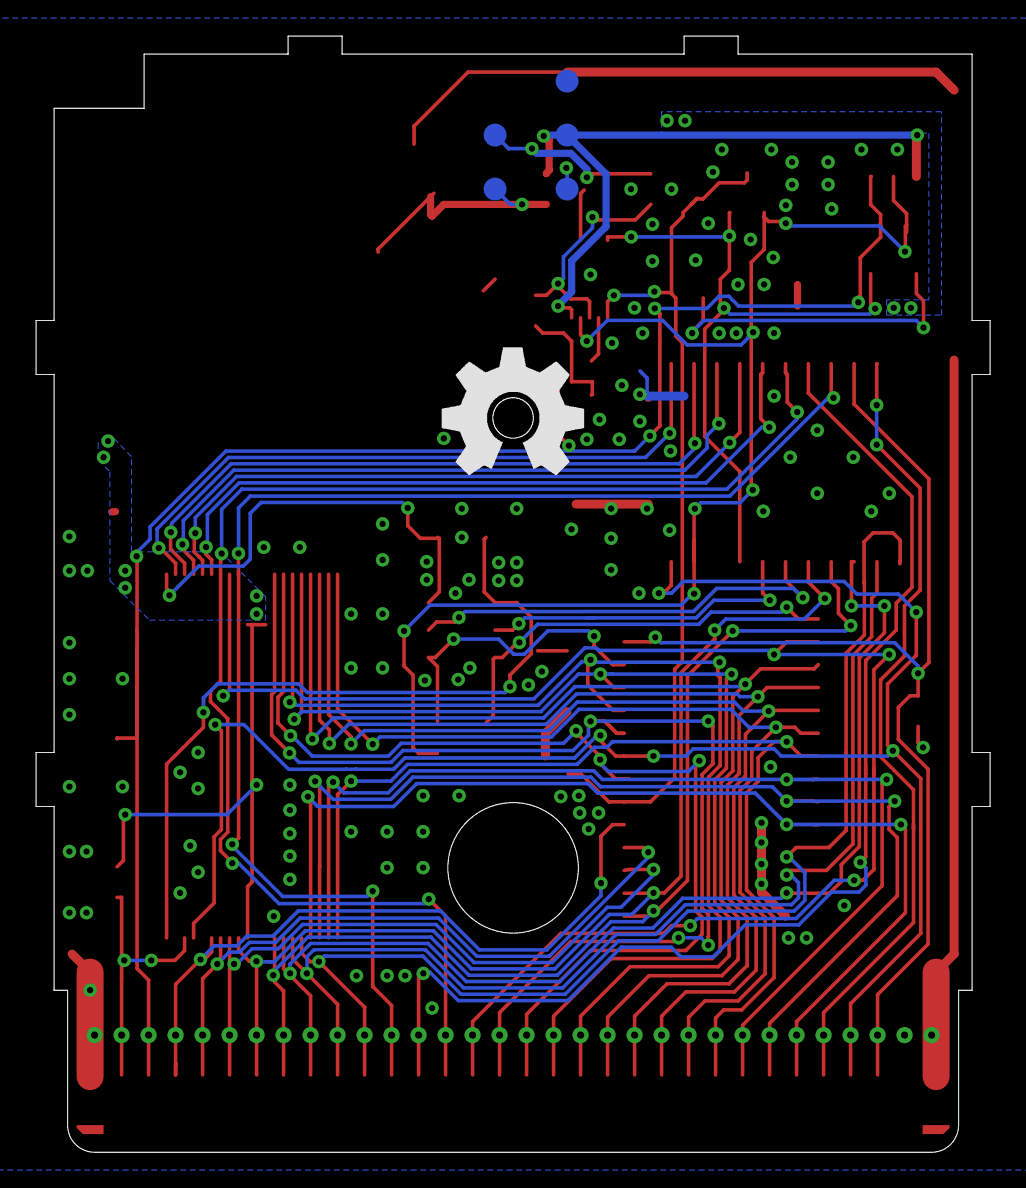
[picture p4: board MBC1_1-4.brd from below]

Board: 2 copper layers, 53.0 x 62.0 mm, 36 parts (5 on the bottom side), 51 nets.
